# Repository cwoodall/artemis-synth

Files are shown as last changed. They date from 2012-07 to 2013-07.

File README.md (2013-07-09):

# Artemis Synthesizer 

v2.0 Rev C for Summer 2013

Christopher Woodall  
Eric Hazen  
Sam Damask

## Hardware

Schematic and PCB files were made using KiCAD. Gerber files and PDFs are available. The schematic files were created using a 25 mil grid and are sometimes off by 25 mils from the 50 mil grid. It is advised that you also use a 25 mil grid when editing the schematic files.

There is a basic convention for digital signals on the PCB layout, which is the bottom layer travels vertically and the top layer travels horizontally. The analog section, which takes up the left most part of the board routes all signals on the top layer so that they have ground right underneath. An improvement would introduce proper isolation technology.

## Firmware

## Documentation

[Current Documentation](http://ohm.bu.edu/cgi-bin/edf/SoundSynthesizer)

## Versioning

The basic versioning method is `Version NUM Rev LETTER (vNUMrLETTER)`. The version number indicates major version changes (and more importantly the associated software version). The revision letter marks the board revision and does not restart with new versions.

Branched projects are allowed to restart revision numbering and version numbering so long as the name of the project changes in some manner. This is requested to prevent confusion.

## Licensing

(c) Christopher Woodall 2012-2013, under a Creative Commons Attribution-ShareAlike 3.0 Unported License.

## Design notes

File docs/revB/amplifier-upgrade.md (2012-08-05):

Need new Audio Amplifier set up....

Try:
* NJM2076D: http://www.digikey.com/product-detail/en/NJM2076D/NJM2076D-ND/638901
* TEA2025B: http://www.digikey.com/product-detail/en/TEA2025B/497-3991-5-ND/715905
* TBD820M: http://www.digikey.com/product-search/en?x=0&y=0&lang=en&site=us&KeyWords=TBA820m

- Offer a speaker and an audiojack (Audio Jack w/ switch)

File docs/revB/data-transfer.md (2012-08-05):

Optoloader is wonderful and cool, but we have a USB link.

Look into using it as a mass storage device, load up a file of some sort generated by online stuff to that... Should work ok... Would allow for arbitrary waveforms

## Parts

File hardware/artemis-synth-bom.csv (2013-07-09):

# of Boards | 30
REFERENCE | VALUE | DISTRIBUTOR | DISTRIBUTOR # | QUANTITY per Board | Total Quantity | Unit Cost (w/ Price Breaks) | Total Cost (per board) | Digikey Ea | Digikey Total | Our total | Diff
BT1 | BATTERY | Digikey | SBH321AS-ND | 1 | 30 | 1.64 | 1.64 | 1.998 | $59.94 | $49.20 | $10.74
C1, C6 | 10uF | Digikey | 399-6100-ND | 2 | 60 | 0.114 | 0.228 | 0.0646 | $3.88 | $6.84 | -$2.96
C2,C3,C4,C5 | .1uF | Digikey | BC2665CT-ND | 4 | 120 | 0.07072 | 0.28288 | 0.0984 | $11.81 | $8.49 | $3.32
D1 | LED GREEN 3MM | Digikey | 754-1217-ND | 1 | 30 | 0.0808 | 0.0808 | 0.0808 | $2.42 | $2.42 | $0.00
D2 | AMBIENT LIGHT SENSOR 3MM 570NM | Digikey | 751-1057-ND | 1 | 30 | 0.4804 | 0.4804 | 0.4804 | $14.41 | $14.41 | $0.00
D3, D4, D5, D6, D7, D8, D9. D10 | RED LED 3mm | Digikey | 754-1219-ND | 8 | 240 | 0.0675 | 0.54 | 0.0743 | $17.83 | $16.20 | $1.63
IC1 | ATMEGA328P | Digikey | ATMEGA328P-PU-ND | 1 | 30 | 0 | 0 | 1.9832 | $59.5 | $0.00 | $59.50
IC1-SOCKET | 28 Pin .3" PDIP Socket | Digikey | A100210-ND | 1 | 30 | 0.411 | 0.411 | 0.411 | $12.33 | $12.33 | $0.00
J1 | AVR-ISP-6 (2x3 .1” header) | Digikey | 952-1921-ND | 1 | 30 | 0.234 | 0.234 | 0.234 | $7.02 | $7.02 | $0.00
J2 | CONN JACK STEREO R/A 3PIN 3.5MM | Digikey | CP1-3523N-ND | 1 | 30 | 0.58 | 0.58 | 0.588 | $17.64 | $17.40 | $0.24
R1 | 220 Ohm 1/4" Mini | Digikey | S220QCT-ND | 1 | 30 | 0.055 | 0.055 | 0.055 | $1.65 | $1.65 | $0.00
R2,R3,R6 | 100K Ohm 1/4" Mini | Digikey | S100KQTR-ND | 3 | 90 | 0.03 | 0.09 | 0.03 | $2.7 | $2.70 | $0.00
R4 | 10K Ohm 1/4" Mini | Digikey | S10KQTR-ND | 1 | 30 | 0.055 | 0.055 | 0.055 | $1.65 | $1.65 | $0.00
R5, R9 | 47K Ohm 1/4" Mini | Digikey | S47KQTR-ND | 2 | 60 | 0.055 | 0.11 | 0.03 | $1.8 | $3.30 | -$1.50
R7,R8 | 1K Ohm 1/4" Mini | Digikey | S1KQTR-ND | 3 | 90 | 0.03 | 0.09 | 0.03 | $2.7 | $2.70 | $0.00
RV1 | 1K Thumbwheel Pot | Digikey | 3352T-1-102LF | 1 | 30 | 1.395 | 1.395 | 1.1664 | $34.99 | $41.85 | -$6.86
SW1, SW2, SW3, SW4, SW5, SW6, SW7, SW8, SW9, SW10 | SWITCH_PUSH_CW | Digikey | CKN9140-ND | 10 | 300 | 0.2794 | 2.794 | 0.3588 | $107.64 | $83.82 | $23.82
U1 | MCP4921 | Digikey | MCP4921-E/P-ND | 1 | 30 | 1.97 | 1.97 | 1.64 | $49.2 | $59.10 | -$9.90
U1-SOCKET | 8 pin .3" PDIP Socket | Digikey | A100204-ND | 1 | 30 | 0.18 | 0.18 | 0.181 | $5.43 | $5.40 | $0.03
STANDOFFS | STANDOFF RD 4-40THR .750"L ALUM | Digikey | 3481K-ND | 4 | 120 | 0.3244 | 1.2976 | 0.3034 | $36.41 | $38.93 | -$2.52
Total (per Board) | 12.51368
Total | 375.4104 |  |  |  |  |  |  |  | $450.95 | $375.41 | $75.5396

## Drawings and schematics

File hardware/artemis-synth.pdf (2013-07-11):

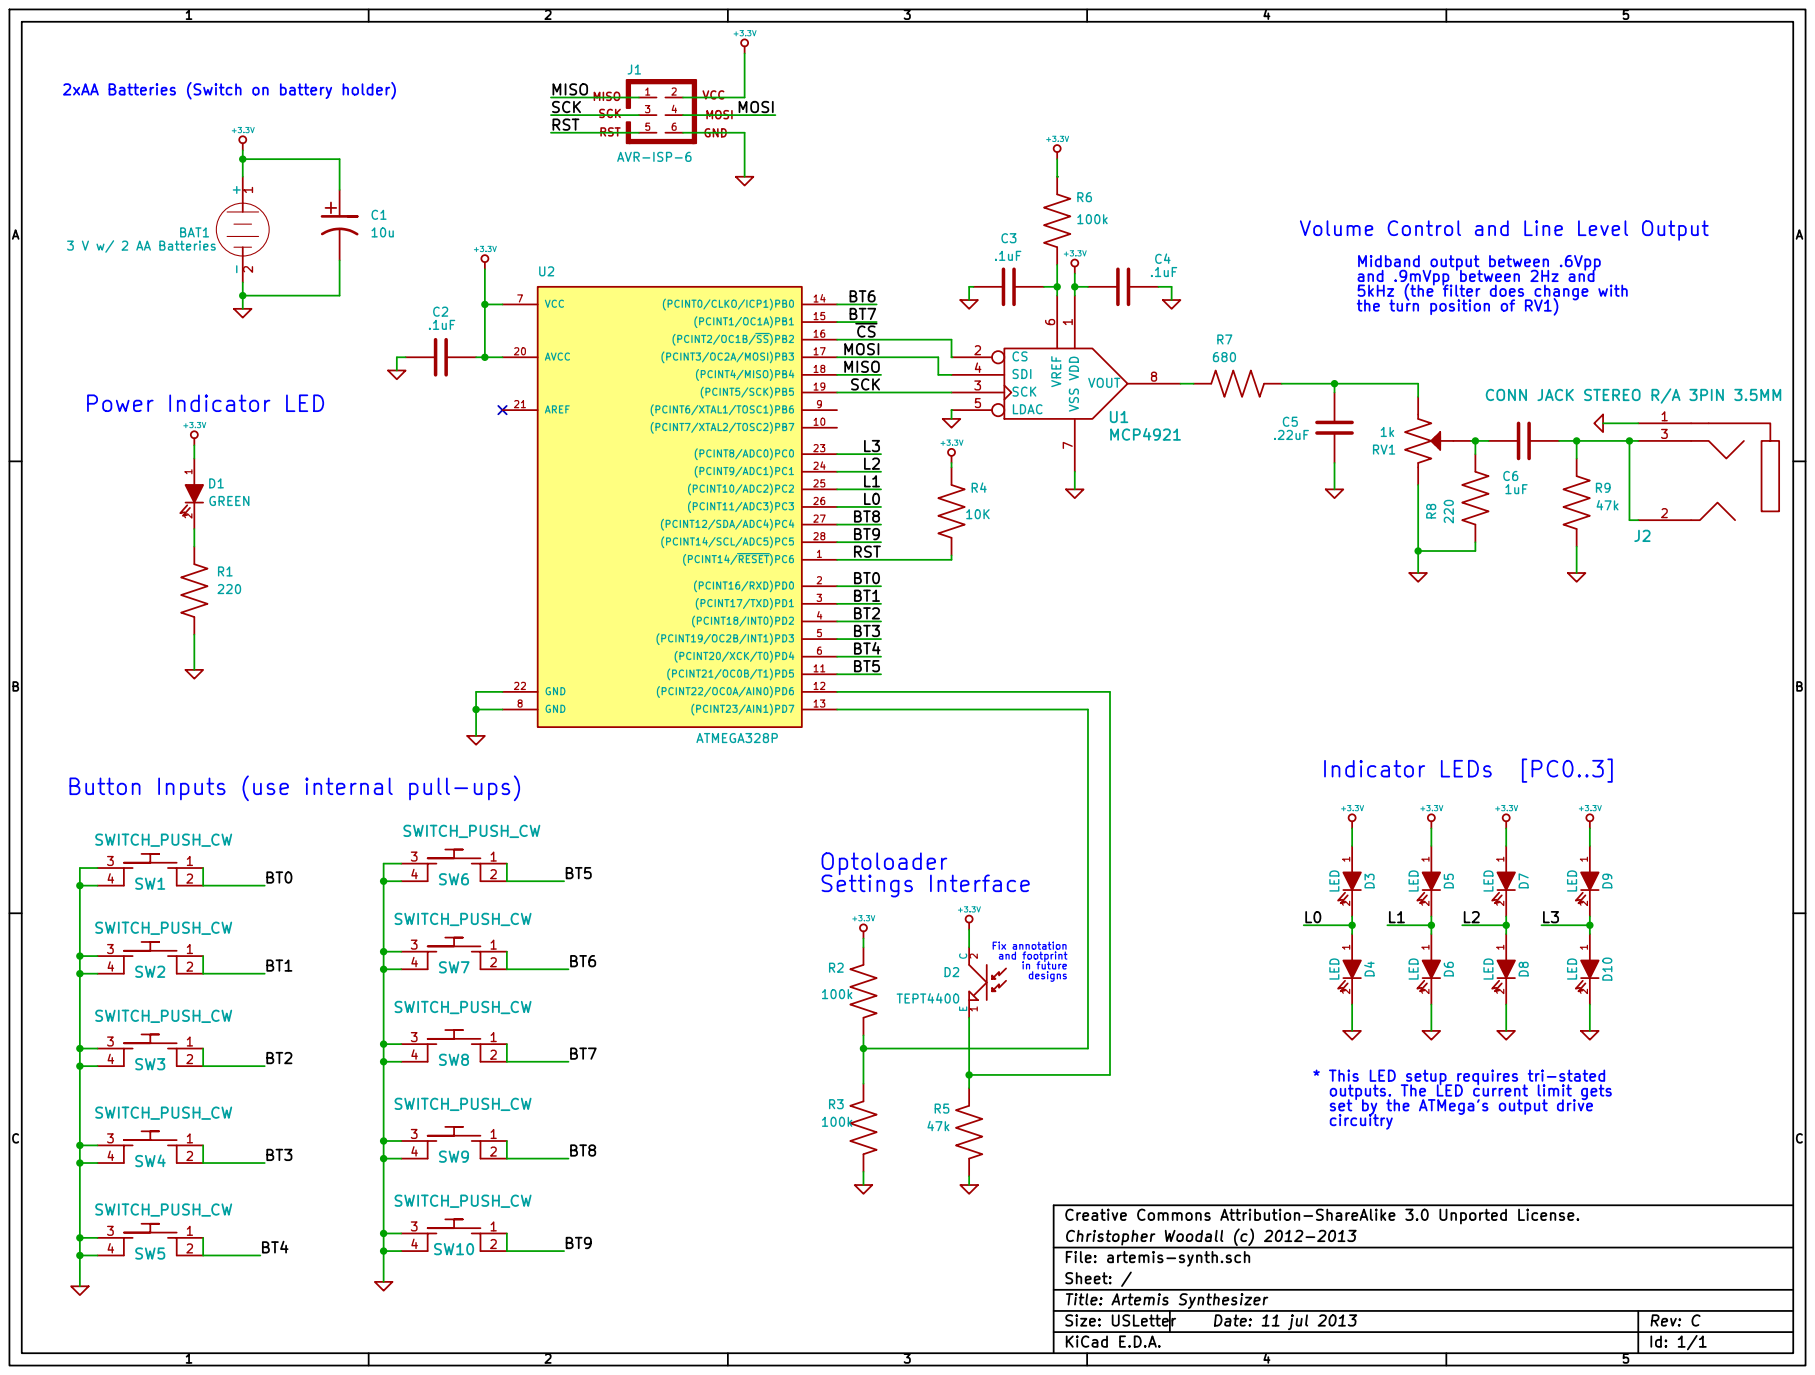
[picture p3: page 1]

+3.3V 2xAA Batteries (Switch on battery holder)

Volume Control and Line Level Output

Midband output between .6Vpp
and .9mVpp between 2Hz and
5kHz (the filter does change with
the turn position of RV1)

* This LED setup requires tri-stated
outputs. The LED current limit gets
set by the ATMega's output drive
circuitry

Creative Commons Attribution-ShareAlike 3.0 Unported License.
Christopher Woodall (c) 2012-2013
File: artemis-synth.sch
Sheet: /
Title: Artemis Synthesizer
KiCad E.D.A.

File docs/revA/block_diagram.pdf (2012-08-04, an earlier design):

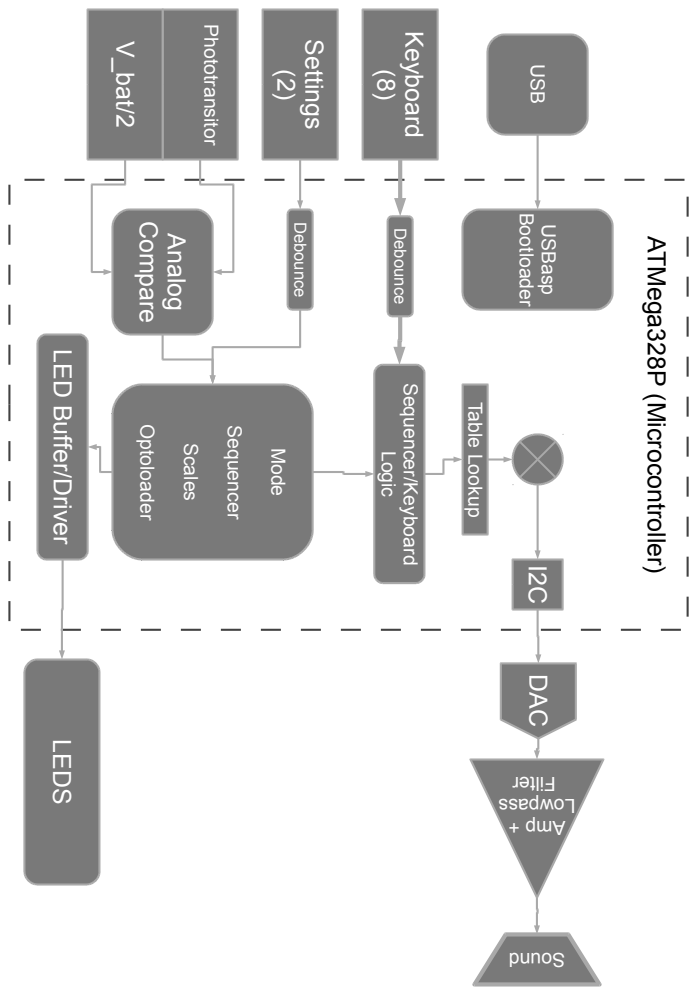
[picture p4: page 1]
ATMega328P (Microcontroller); Keyboard; Sequencer/Keyboard; Logic Debounce; Table Lookup; Settings (2) Debounce; Phototransitor; V_bat/2; Analog; Compare; Mode; Sequencer; Scales; Optoloader; USBasp; Bootloader USB

LED Buffer/Driver LEDS

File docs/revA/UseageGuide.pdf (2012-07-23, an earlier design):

# Keyboard Mode

# ARTEMIS Synthesizer Usage Guide

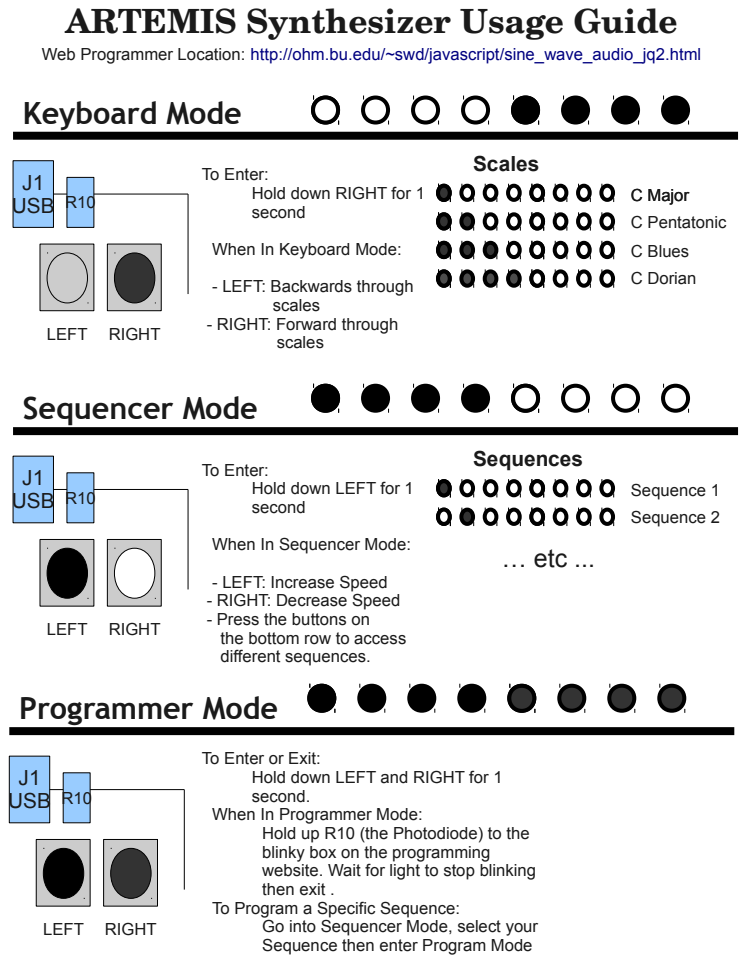
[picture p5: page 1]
USB; LEFT RIGHT; scales; Scales; C Major C Pentatonic; C Blues C Dorian; Sequencer Mode; Sequences; Sequence 1 Sequence 2; … etc ...; J1 USB R10; Programmer Mode

Web Programmer Location: http://ohm.bu.edu/~swd/javascript/sine_wave_audio_jq2.html

To Enter:
Hold down RIGHT for 1
second

When In Keyboard Mode:

- LEFT: Backwards through

- RIGHT: Forward through

Hold down LEFT for 1

When In Sequencer Mode:

- LEFT: Increase Speed
- RIGHT: Decrease Speed
- Press the buttons on
the bottom row to access
different sequences.

To Enter or Exit:
Hold down LEFT and RIGHT for 1
second.
When In Programmer Mode:
Hold up R10 (the Photodiode) to the
blinky box on the programming
website. Wait for light to stop blinking
then exit .
To Program a Specific Sequence:
Go into Sequencer Mode, select your
Sequence then enter Program Mode

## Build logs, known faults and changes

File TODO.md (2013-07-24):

# TODO

* Fix D2 footprint to represent what it really is and also make long lead == square hole. (long lead goes to E)

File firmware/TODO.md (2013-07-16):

# TODO LIST

* Make one button switch scales and the other octaves

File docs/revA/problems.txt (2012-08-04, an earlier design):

<h1 id="problems">Problems:</h1>

<ul>
<li>We did not have 28-pin sockets so we used 2 14 pin sockets so some were not aligned properly. Check your BOM for parts and dimensions!</li>
<li>No 8 pin sockets so if the DAC or Amp were put in wrong a lot of effort needed to go into rework. SOCKET ALL PINS.</li>
<li>Some had issues getting R10 into place correctly and bending. It is a polarized part and needs to be put in right; however, the polarization is not labeled. Needs to be redesigned in future revisions. This will simplify the instructions</li>
<li>Volume too low for the most part. Needs to be fixed in future revisions. A constant complaint.</li>
<li>Web programming rig was effective, but I have some concerns about the actual usability of it. It is slow, and can be unreliable.</li>
</ul>

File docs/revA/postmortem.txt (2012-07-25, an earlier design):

# Post Mortem

## Project Timeline Review

### Brainstorm (June 12-15th)
We decided to develop a project of our own on June 12, 2012. At which point we
presented a few basic options for the project. The two competitors were a 
**Game of Life simulator** or a **synthesizer**. By June 15th we decided on the
synthesizer, ordered test components, decided on a microprocesor and were ready
to start the prototyping stages. 

### Prototypes (June 18th-22nd)

The audio amplifier was prototyped on perfboard
by June 20th and written up [here](http://happyrobotlabs.com/posts/project/artemis-synthesizer-1-testing-the-tda2822-audio-amplifier/).
The TDA2822 test was successful, but the volume output of the speaker was low 
and as would be noted later was not very impressive

The MCP4921 was prototyped and documented [here](http://happyrobotlabs.com/posts/project/artemis-synthesizer-2-interfacing-with-the-mcp4921-spi-dac/).
The process was very swift and there were no major problems. Powering the SPI 
bus from the arduino which was 5V based required power limiting resistors.

### Schematic and PCB layout (June 25-July 6)

Most of the schematic layout was done during the prototyping stages in KiCAD.
KiCAD was very easy to use, but I needed to upgrade to the latest version in
order for it to be especially useable. Schematic layout went without a hitch.

PCB layout started once all the parts were chosen a BOM was made up and 
everything was layed out. PCB orders went out to Sierra Circuits and after
some tweaking to their rules and limits we were able to print with them. 
However, upon receiving the boards there was one trace shorted to the 3.3V
plane making the USB bootloader unuseable on this board. This problem was 
limited to one board and after testing most of the rest was not reproduceable.
In the future, I would increase the boundary between traces and planes and 
possibly avoid power planes for simple designs. 

There were some funding problems since the PCB boards ended up costing around
$15 per and parts also costed nearly $15 per board. The BOM cost was rather 
high for this project and an inspection should be carried out to find cost 
reductions for future revisions of the board.

### Firmware (July 12-20) 

Firmware development went well. Code could be better commented. Needs to be 
cleaned. Make sure comment frequently in future projects and write libraries
for the various "peripherals" you use (internal or external). If you have good
interfaces/drivers then other people can use your board even if your base 
firmware is a little sketchy.

Also, figure out a way to formalize different program states/tasks/programs with
efficient memory management. First time using interrupts heavily. Make sure 
interrupts, especially timer interrupts, are small. There are times when
interrupts can be lengthy, but be cautious and evaluate everything that could 
happen while that interrupt is happening and make the system as robust as 
possible.

### Packing (July 18-20)

Packing went smoothly, but took a lot of work. Need to make sure you put exactly
the right number of parts in. To many confuses people and to few makes the kit
impossible to complete correctly.

We also found some BOM errors. Always check your footprints!

## Additional Problems and Comments

* Audio quiet. Inspect whole audio amplification circuit. Possibly look for a new 
  speaker.

* BOM cost was high.
  * Possibly remove DAC use PWM instead
  * Possibly smaller microcontroller ATMega168 or ATMega88 vs ATMega328

* During soldering many had IC problems
  * Buy the correct sockets
  * Socket all ICs not just the MCU makes, rework easier.

* R10 is polarized, but not labelled as such. Rework Optoloader circuit

* Optoloader speed problems. A very slow data transmission.
  * Possibly use 2 photodiodes (separate clock and data lines)
  * Possibly use multiple colors (interesting solution, but likely expensive)
  * Ditch javascript and try flash, gifs, movies, etc.
  * If speeds can be significantly improved, then we can start programming more 
    complex things over the link.

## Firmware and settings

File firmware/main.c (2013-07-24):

/** 
 *  Artemis Synthesizer v2.00 Firmware
 *  Date: 2013-07-15  
 *
 *  Copyright (c) 2012-2013 Christopher Woodall 
 *  MIT License
 */
#define F_CPU 8000000 // Used to run at 16MHz, but removed XTAL now runs at 8kHz
#include <avr/io.h>
#include <avr/interrupt.h>
#include <util/atomic.h>
#include <avr/eeprom.h> 

#include "HRL_SPI.h"
#include "HRL_MCP492x.h"
#define MCP492x_CONFIG 0x30 // Define configuration bits for MCP4921, that we are going to use

#include "notes.h"
#include "inst.h"
#include "buttons.h"
#include "leds.h"
#include "optoloader.h"

uint8_t opto_enable_ctr = 0;
uint8_t keyboard_ctr = 0;
uint8_t sequencer_ctr = 0;
uint8_t msg_ctr = 0;
uint8_t speed = 0x5F;

#define KEYBOARD  0x01
#define SEQUENCER 0x02
#define BLINKING  0x03
#define OPTOLOADER 0x04 // Currently not used, maintianed by optoloader.flag...
uint8_t mode = KEYBOARD;

#define SEQUENCER_LENGTH 8
#define TOTAL_SEQUENCES 8
uint8_t sequencer_i = 0;

//#define SEQUENCER_ee (const void*)12
uint8_t EEMEM sequencer_ee[TOTAL_SEQUENCES][SEQUENCER_LENGTH] = {
	{0,0,0,0,0,0,0,0},
	{0,0,0,0,0,0,0,0},
	{0,0,0,0,0,0,0,0},
	{0,0,0,0,0,0,0,0},
	{0,0,0,0,0,0,0,0},
	{0,0,0,0,0,0,0,0},
	{0,0,0,0,0,0,0,0},
	{0,0,0,0,0,0,0,0}
};

uint8_t EEMEM first_ee = 0x00;

uint8_t sequencer[TOTAL_SEQUENCES][SEQUENCER_LENGTH] = {
	{0,0,0,0,0,0,0,0},
	{0,0,0,0,0,0,0,0},
	{0,0,0,0,0,0,0,0},
	{0,0,0,0,0,0,0,0},
	{0,0,0,0,0,0,0,0},
	{0,0,0,0,0,0,0,0},
	{0,0,0,0,0,0,0,0},
	{0,0,0,0,0,0,0,0}
};

uint8_t sequencer_display_i = 0;
uint8_t sequencer_metronome = 0;
uint8_t sequencer_metronome_ctr = 0;
uint8_t sequencer_flag = 0;

// WAVE/HARMONICS stuff
uint16_t harmonics[256];
uint16_t harmonics_amplitudes[5] = {0,0,0,0,0};

// LED, Optoloader and Keyboard globals
uint8_t led_refresh_flag = 0;
uint8_t led_display = 0x00000000;
optoloader_t optoloader;
uint8_t read_keyboard_flag = 0;
uint8_t settings_debounce = 0;

#define MAX_LOOKUP  0x7FFF
// Change to inline function
#define GET_WAVE_VALUE(inst, num) (poly_buffer[num]?inst[inc[num]>>NOTES_BASE]:0)
// Change to inline function
#define INCREMENT_NOTE(note, i)                 \
	if (note)									\
    {                                           \
		if (i + note < MAX_LOOKUP)				\
        {                                       \
			i += note;							\
        }                                       \
		else									\
        {                                       \
			i = note - (MAX_LOOKUP - i);		\
        }                                       \
    }                                           \
	else										\
    {                                           \
		i = 0;									\
    }							

// Setup Sample rate at 11kHz, externally we filter at 5.5kHz
// this satisfies Nyquist and technically we should be able
// to accurately reconstruct waves up to 5.5kHz, more than enough 
// for this application.
void setupSampleRate11kHz();

// Setup controls timer at a much lower frequency (near 300Hz)
void setupControlTimer();

#define SCALE_LENGTH 8
uint8_t scale_i = 0;
uint16_t scales[4][SCALE_LENGTH] = {
  {C5, D5, E5, F5, G5, A5, B5, C6},
  {C5, D5, E5, G5, A5, C6, D6, E6},
  {C5, Ds5, F5, Fs5, G5, As5, C6, Ds6},
  {C5, D5, Ds5, F5, G5, A5, As5, C6}
};

uint16_t poly_buffer[8] = {0,0,0,0,0,0,0,0};
uint8_t poly_i = 0;
uint8_t key_pressed;
uint8_t debounce = 0;

inline uint8_t shiftOnes(uint8_t a) 
{
	uint8_t output = 0;
	uint8_t i = 0;
	for (i = 0; i < a; i++) {
		output |= (1<<i);
	}
	return output;
}

int main(void)
{
	// Disable Interrupts for setup
	cli();
	
	// By default load a sine_table wave into harmonic 
	// [*] replace with EEPROM reads
	for (int i = 0; i < 256; i++) {
		harmonics[i] = sine_table[i];
    }
	
	first_ee = eeprom_read_byte(&first_ee);
	if (first_ee == 0xFF) {
		eeprom_write_byte(&first_ee,0x33);
		eeprom_write_block((const void *)sequencer, (void *)sequencer_ee, 64);
    } else {
		// Load up sequencer information from ee_prom
		eeprom_read_block((void*)sequencer, (const void *)sequencer_ee, 64);
    }
	
	// Setup Timer2, which is our "control timer"
	setupControlTimer();
	
	// SETUP BUTTON INPUTS
	setupButtons();
	
	// Setup the SPI Bus
	setupSPI(SPI_MODE_0, SPI_MSB, SPI_NO_INTERRUPT, SPI_MASTER_CLK2);
	SETUP_DAC;
	
	// Setup Timer1 to work at 22KHz sample rate
	// This is our sample rate for the output audio
	setupSampleRate11kHz(); 
  
	// Initialize display for keyboard mode
	led_display = setupDisplay();
	setDisplay(&led_display, shiftOnes(scale_i+1));  
	
	// Initialize Optoloader and then turn it off
	optoloader = setupOptoloader();
	disableOptoloader(&optoloader);
	
	// For storing settings button presses
	uint8_t settings = 0;
	uint8_t settings_prev = 0;
	uint8_t keyboard = 0;
	uint8_t keyboard_prev = 0;
	
	
	sei(); // Enable Interrupts now that we are all ready to go
	for(;;) {
		updateDisplay(&led_display, &led_refresh_flag);
		
		settings = readSettings();
		// Check if we are in Optoloader mode (active Optoloader)
		if (optoloader.flags & OPTO_ACTI_bm) {
			if (settings_debounce == 0) {	
				if ((settings == 0) && (settings_prev != 0)) {
					opto_enable_ctr = 1;
					settings_debounce = 1;
				} else if ((settings != 0) && (settings_prev == 0))	{
					settings_debounce = 1;
					opto_enable_ctr = 0;
				}
			}	  
		} else {
			if ((settings == 0) && (opto_enable_ctr == 0)) {
				opto_enable_ctr = 1;
				sequencer_ctr = 0;
				keyboard_ctr = 0;
			} else if (settings) {
				opto_enable_ctr = 0;
				if (!(settings & 0x02) && (sequencer_ctr == 0))	{
					sequencer_ctr = 1;
				} else if (settings & 0x02)	{
					sequencer_ctr = 0;
				}
				if (!(settings & 0x01) && (keyboard_ctr == 0)) {
					keyboard_ctr = 1;
				} else if (settings & 0x01)	{
					keyboard_ctr = 0;
				}
			}
	  
			if (mode == KEYBOARD) {
				if (settings_debounce == 0)	{	
					if (((settings & 0x01) == 0) && ((settings_prev & 0x01) != 0)) { 
						if (scale_i < 3) {
							scale_i += 1;
						} else {
							scale_i = 0;
						}
						settings_debounce = 1;
						setDisplay(&led_display, shiftOnes(scale_i+1));
					}
					if (((settings & 0x02) == 0) && ((settings_prev & 0x02) != 0)) {
						if (scale_i > 0) {
							scale_i -= 1;
						} else {
							scale_i = 3;
						}
						setDisplay(&led_display, shiftOnes(scale_i+1));		  
						settings_debounce = 1;
					}
				}
				if (read_keyboard_flag) {
					read_keyboard_flag = 0;
					keyboard = readKeyboard();
					
					// Prevent the following array accesses to be disturbed, otherwise you get nasty sounds
					ATOMIC_BLOCK(ATOMIC_RESTORESTATE) {
						poly_buffer[0] = 0;
						poly_buffer[1] = 0;
						poly_buffer[2] = 0;
						poly_buffer[3] = 0;
						poly_buffer[4] = 0;
						poly_buffer[5] = 0;
						poly_buffer[6] = 0;
						poly_buffer[7] = 0;
						
						poly_i = 0;
						
						for (uint8_t j = 0; j < 8; j++) {
							if (((keyboard & (0x01 << j)) == 0) && (poly_i <= 3)) {
								poly_buffer[poly_i] = scales[scale_i][j];
								poly_i += 1;
							}
						}
					}
				}
			} else if (mode == SEQUENCER) {
				//setDisplay(&led_display, sequencer_metronome);
				setDisplay(&led_display, shiftOnes(sequencer_i+1));
				
				keyboard = readKeyboard();
				if (settings_debounce == 0)	{
					if (((settings & 0x02) == 0) && ((settings_prev & 0x02) != 0)) { 
						if (speed < 0xCF) {
							speed += 0x10;
						} else {
							speed = 0xCF;
						}
						settings_debounce = 1;
						setDisplay(&led_display, shiftOnes(scale_i+1));
					}

					if (((settings & 0x01) == 0) && ((settings_prev & 0x01) != 0)) {
						if (speed > 0x2F) {
							speed -= 0x10;
						} else {
							speed = 0x2F;
						}
						settings_debounce = 1;
					} 

					if (((keyboard & 0x01)==0) && ((keyboard_prev & 0x01) != 0)) {
						sequencer_i = 0;
						settings_debounce = 1;
					}
					if (((keyboard & 0x02)==0) && ((keyboard_prev & 0x02) != 0)) {
						sequencer_i = 1;
						settings_debounce = 1;
					}
					if (((keyboard & 0x04)==0) && ((keyboard_prev & 0x04) != 0)) {
						sequencer_i = 2;
						settings_debounce = 1;
					}

					if (((keyboard & 0x08)==0) && ((keyboard_prev & 0x08) != 0)) {
						sequencer_i = 3;
						settings_debounce = 1;
					}

					if (((keyboard & 0x10)==0) && ((keyboard_prev & 0x10) != 0)) {
						sequencer_i = 4;
						settings_debounce = 1;
					}

					if (((keyboard & 0x20)==0) && ((keyboard_prev & 0x20) != 0)) {
						sequencer_i = 5;
						settings_debounce = 1;
					} 

					if (((keyboard & 0x40)==0) && ((keyboard_prev & 0x40) != 0)) {
						sequencer_i = 6;
						settings_debounce = 1;
					} 

					if (((keyboard & 0x80)==0) && ((keyboard_prev & 0x80) != 0)) {
						sequencer_i = 7;
						settings_debounce = 1;
					}
				}
				keyboard_prev = keyboard;
				poly_i = 4;
				
				ATOMIC_BLOCK(ATOMIC_RESTORESTATE) {
					sequencer_flag = 0;
					if (sequencer[sequencer_i][sequencer_metronome] & (1<<0)) {
						poly_buffer[0] = C5;
					} else {
						poly_buffer[0] = 0;
					} 
					if (sequencer[sequencer_i][sequencer_metronome] & (1<<1)) {
						poly_buffer[1] = D5;
					} else {
						poly_buffer[1] = 0;
					}
					if (sequencer[sequencer_i][sequencer_metronome] & (1<<2))	{
						poly_buffer[2] = E5;
					} else {
						poly_buffer[2] = 0;
					}
					if (sequencer[sequencer_i][sequencer_metronome] & (1<<3))	{
						poly_buffer[3] = F5;
					} else {
						poly_buffer[3] = 0;
					}
					if (sequencer[sequencer_i][sequencer_metronome] & (1<<4))	{
						poly_buffer[4] = G5;
					} else {
						poly_buffer[4] = 0;
					} 
					if (sequencer[sequencer_i][sequencer_metronome] & (1<<5))	{
						poly_buffer[5] = A5;
					} else {
						poly_buffer[5] = 0;
					}
					if (sequencer[sequencer_i][sequencer_metronome] & (1<<6))	{
						poly_buffer[6] = B5;
					} else {
						poly_buffer[6] = 0;
					}
					if (sequencer[sequencer_i][sequencer_metronome] & (1<<7))	{
						poly_buffer[7] = C6;
					} else {
						poly_buffer[7] = 0;
					}
				}
			}
		}
		settings_prev = settings;
	}
	return 0;
}

void setupControlTimer()
{    
	TCCR2A = 0;     // set entire TCCR1A register to 0
	TCCR2B = 0;     // same for TCCR1B
	TIMSK2 = 0;
	TCNT2 = 0;

	// target_freq = 306.4 Hz
	// timer_res = 1/16MHz
	// prescaler = 1024
	// timer_counts = (1.0/target_freq)/(timer_res*prescaler) - 1
	OCR2A = 50; 
  
	// Turn on CTC mode
	TCCR2A |= (1 << WGM21);
	// set CS20, CS21 & CS22 for 1024 precaler
	TCCR2B |= (1 << CS20);
	TCCR2B |= (1 << CS21);
	TCCR2B |= (1 << CS22);

	// Enable interrupts
	TIMSK2 |= (1 << OCIE2A);
}

ISR(TIMER2_COMPA_vect)
{
	read_keyboard_flag = 1;
	if (optoloader.flags & OPTO_ACTI_bm) {
		optoloader.counter += 1;
		if (opto_enable_ctr == 0xFF) {
			optoloader.flags &= ~OPTO_ACTI_bm;
			setDisplay(&led_display, shiftOnes(scale_i+1));
			disableOptoloader(&optoloader);
			opto_enable_ctr = 0;
			
			eeprom_write_block((const void *)sequencer, (void *)sequencer_ee, 64);

			setupSampleRate11kHz();
		} 
		
		if (opto_enable_ctr > 0) {
			opto_enable_ctr += 1;
		}      
	} else {
		if (opto_enable_ctr == 0xFF) {
			optoloader.flags |= OPTO_ACTI_bm;
			setDisplay(&led_display, 0xFF);
			TCNT2 = 0;      
			TCCR1B = 0;
			enableOptoloader(&optoloader);
			opto_enable_ctr = 0;
			msg_ctr = 0;
		} else if (opto_enable_ctr > 0) {
			opto_enable_ctr += 1;
		}

		if (sequencer_ctr == 0xFF) {
			setDisplay(&led_display, 0x0F);
			sequencer_ctr = 0;
			mode = SEQUENCER;
		} else if (sequencer_ctr > 0) {
			sequencer_ctr += 1;
		}

		if (keyboard_ctr == 0xFF) {
			setDisplay(&led_display, 0xF0);
			keyboard_ctr = 0;
			mode = KEYBOARD;
		} else if (keyboard_ctr > 0) {
			keyboard_ctr += 1;
		}

		if (mode == SEQUENCER) {
			sequencer_metronome_ctr += 1;
			if ((sequencer_metronome_ctr >= speed) && !(sequencer_metronome % 2)) {
				sequencer_metronome += 1;
				sequencer_metronome_ctr = 0;
				sequencer_flag = 1;
			} else if ((sequencer_metronome_ctr >= (speed-0x05))) {
				sequencer_metronome += 1;
				sequencer_metronome_ctr = 0;
				sequencer_flag = 1;
			} 

			if (sequencer_metronome > 7){
				sequencer_flag = 1;
				sequencer_metronome = 0;
			}
		}
	}

	if (settings_debounce == 30) {
		settings_debounce = 0;
	} else if (settings_debounce >= 1) {
		settings_debounce += 1;
	}

	led_refresh_flag ^= 0x01;
	led_refresh_flag |= 0x02;
}

ISR(ANALOG_COMP_vect)
{
	static uint8_t num_bytes = 0; // number of bytes expected to be received

	static uint32_t temp_harmonics = 0;
	static uint8_t msg_mode = 0; 
	// Turn off Timer 2 Interrupt A
	TIMSK2 &= ~(1<<OCIE2A);
	// Reset Timer2 Counter
	TCNT2 = 0;

	// Get optoloader information
	runOptoloader(&optoloader, &led_display);

	// When we have a full byte, read it out and display it.
	if (optoloader.message_count == 8) {
		optoloader.message_count = 0;
		led_display = optoloader.message;

		// NEED TO FINISH WRITING MESSAGE INTERPRETATION STUFF
		if (msg_ctr == 0) {
			if (optoloader.message & SEQUENCER_MSG) {
				// if we are getting a sequencer message do something here
				msg_mode = SEQUENCER_MSG;
			} else if (optoloader.message & HARMONICS_MSG) {
				// if we are getting a harmonics message do the appropraite thing here
				msg_mode = HARMONICS_MSG;
			} //else {
				// ERROR STATE!!!
//			}
			// How many bytes before epilogue?
			num_bytes = 0x0F & optoloader.message;
		} else if (msg_ctr > num_bytes)	{
			if (optoloader.message == EPILOGUE_MSG)	{ 
				if (msg_mode == HARMONICS_MSG)	{
					for (uint16_t i = 0; i < 256; i++) {
						// Simplify this code...
						// Also % 256 -> and 255 (& 255)
						temp_harmonics = (((harmonics_amplitudes[0]*(sine_table[i]<<2))>>4) + 
															((harmonics_amplitudes[1]*(sine_table[(i*2)%256]<<2))>>4) + 
															((harmonics_amplitudes[2]*(sine_table[(i*4)%256]<<2))>>4) + 
															((harmonics_amplitudes[3]*(sine_table[(i*8)%256]<<2))>>4) + 
															((harmonics_amplitudes[4]*(sine_table[(i*16)%256]<<2))>>4))/5;

						harmonics[i] = (uint16_t) temp_harmonics;
					}
				}
				opto_enable_ctr = 0xFF;
			}
		} else if (msg_ctr > 0) {
			if (msg_mode == SEQUENCER_MSG) {
				sequencer[sequencer_i][msg_ctr-1] = optoloader.message;
			} else if (msg_mode == HARMONICS_MSG) {
				harmonics_amplitudes[(optoloader.message>>5)] = (optoloader.message>>2) & 0x07;
			}
		}
		msg_ctr += 1;
	}
	
	TIMSK2 |= (1<<OCIE2A);
}

void setupSampleRate11kHz()
{    
	TCCR1A = 0;     // set entire TCCR1A register to 0
	TCCR1B = 0;     // same for TCCR1B
	
	// set compare match register to desired timer count:
	// We want to compare at 11kHz
	// target time/timer resolution
	// (1/11kHz)/(1/8MHz) = 727
	OCR1A = 727; 
	
	// turn on CTC mode:
	TCCR1B |= (1 << WGM12);
	TCCR1B |= (1 << CS10); // No prescaler
	// enable timer compare interrupt:
	TIMSK1 |= (1 << OCIE1A);
}

   
ISR(TIMER1_COMPA_vect) 
{
	static uint16_t inc[8] = {0, 0, 0, 0, 0, 0, 0, 0};
	static uint16_t final = 0;
	
	INCREMENT_NOTE(poly_buffer[0], inc[0]);
	INCREMENT_NOTE(poly_buffer[1], inc[1]);
  INCREMENT_NOTE(poly_buffer[2], inc[2]);
	INCREMENT_NOTE(poly_buffer[3], inc[3]);
	INCREMENT_NOTE(poly_buffer[4], inc[4]);
	INCREMENT_NOTE(poly_buffer[5], inc[5]);
	INCREMENT_NOTE(poly_buffer[6], inc[6]);
	INCREMENT_NOTE(poly_buffer[7], inc[7]);
	
	final = (GET_WAVE_VALUE(harmonics, 0) + 
					 GET_WAVE_VALUE(harmonics, 1) +
					 GET_WAVE_VALUE(harmonics, 2) +
					 GET_WAVE_VALUE(harmonics, 3) +
					 GET_WAVE_VALUE(harmonics, 4) +
					 GET_WAVE_VALUE(harmonics, 5) +
					 GET_WAVE_VALUE(harmonics, 6) +
					 GET_WAVE_VALUE(harmonics, 7))>>2;
	
	writeMCP492x(final, MCP492x_CONFIG);
}

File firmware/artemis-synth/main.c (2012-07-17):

#define F_CPU 16000000
#include <avr/io.h>
#include <util/delay.h>
#include <avr/interrupt.h>
#include "HRL_SPI.h"
#include "HRL_MCP492x.h"
#define MCP492x_CONFIG 0x30 // Define configuration bits for MCP4921

#include "notes.h"
#include "inst.h"
#include "buttons.h"
#include "leds.h"

uint8_t led_display = 0x00000000;

#define MAX_LOOKUP  0x7FFF
#define INCREMENT_NOTE(note, i) 			\
  if (note)						\
    {							\
      if (i + note < MAX_LOOKUP)			\
        {						\
          i += note;					\
        }						\
      else						\
        {						\
          i = note - (MAX_LOOKUP - i);			\
        }						\
    }							\
  else							\
    {							\
      i = 0;						\
    }							

#define FREQUENCY_TO_COUNT(x) (F_CPU/1000)/(x/1000)

// Setup Sample rate at 22kHz, externally we filter at 11kHz
// this satisfies Nyquist and technically we should be able
// to accurately reconstruct waves up to 11kHz
void setupSampleRate();
void setupControlTimer();

uint8_t read_keyboard_flag = 0;
#define SCALE_LENGTH 8
#define SCALE_NUMBER 4
uint8_t scale_i = 0;
uint16_t scales[SCALE_NUMBER][SCALE_LENGTH] = {
  {C6, D6, E6, F6, G6, A6, B6, C7},
  {C5, D5, E5, G5, A5, C6, D6, E6},
  {C5, Ds5, F5, Fs5, G5, As5, C6, Ds6},
  {C5, D5, Ds5, F5, G5, A5, As5, C6}
};

uint16_t poly_buffer[4] = {0,0,0,0};
uint8_t poly_i = 0;
uint8_t key_pressed;
uint8_t debounce = 0;
uint8_t settings_debounce = 0;

int main(void) 
{
  // Disable Interrupts for setup
  cli();
  
  // SETUP BUTTON INPUTS
  setupButtons();
  
  setupDisplay();

  // Setup the SPI Bus
  setupSPI(SPI_MODE_0, SPI_MSB, SPI_NO_INTERRUPT, SPI_MASTER_CLK2);
  SETUP_DAC;
  setupSampleRate(22000); // Setup Timer1 to work at 22KHz sample rate
  setupControlTimer();

  uint8_t settings = 0;
  uint8_t settings_prev = 0;

  led_display = 0b11111111;

  sei(); // Enable Interrupts now that we are all ready to go

  for(;;) 
    {      
        settings = readSettings();
        if (settings_debounce == 0)
        {

          if (((settings & 0x02) == 0) && ((settings_prev & 0x02) != 0))
            { 
              led_display <<= 1;
              led_display |= 0x01;
              if (scale_i < 3)
                {
                  scale_i += 1;
                }
              else
                {
                  scale_i = 0;
                }
              settings_debounce = 1;
            }
          if (((settings & 0x01) == 0) && ((settings_prev & 0x01) != 0))
            {
              led_display >>= 1;
              if (scale_i > 0) 
                {
                  scale_i -= 1;
                }
              else
                {
                  scale_i = 3;
                }
              settings_debounce = 1;
            }
        }
      settings_prev = settings;
    }
  
  return(0);
}

void setupControlTimer()
{    
  TCCR2A = 0;     // set entire TCCR1A register to 0
  TCCR2B = 0;     // same for TCCR1B
  TIMSK2 = 0;
  TCNT2 = 0;
  // target_freq = 120 Hz
  // timer_res = 1/16MHz
  // prescaler = 1024
  // timer_counts = (1.0/target_freq)/(timer_res*prescaler) - 1
  OCR2A = 129; 

  // Turn on CTC mode
  TCCR2A |= (1 << WGM21);
  // set CS20, CS21 & CS22 for 1024 precaler
  TCCR2B |= (1 << CS20);
  TCCR2B |= (1 << CS21);
  TCCR2B |= (1 << CS22);

  // Enable interrupts
  TIMSK2 |= (1 << OCIE2A);
}

ISR(TIMER2_COMPA_vect)
{
  static uint8_t keyboard = 0;
  static uint8_t j = 0; 
  static uint8_t led_refresh_flag = 0;
  /*
  keyboard = readKeyboard();
  poly_buffer[0] = 0;
  poly_buffer[1] = 0;
  poly_buffer[2] = 0;
  poly_buffer[3] = 0;
  poly_i = 0;
  
  for (j = 0; j < 8; j++) 
    {
      if (((keyboard & (0x01 << j)) == 0) && (poly_i <= 3))
        {
          poly_buffer[poly_i] = scales[scale_i][j];
          poly_i += 1;
        }
    }
    *
  if (settings_debounce > 0)
    {
      (settings_debounce < 20)?(settings_debounce += 1):(settings_debounce = 0);
    }
  

  PORTC &= 0xF0;
  DDRC &= 0xF0;
  if (led_refresh_flag)
    {
      led_refresh_flag = 0;
      if (led_display & 1)
        {
          PORTC &= LED0_m;
          DDRC |= ~LED0_m;
        }
      else
        {
          DDRC &= LED0_m;
        }
      if ((led_display & (1<<2)) != 0)
        {
          PORTC &= LED2_m;
          DDRC |= ~LED2_m;
        }
      else
        {
          DDRC &= LED2_m;
        }
      if ((led_display & (1<<4)) != 0)
        {
          PORTC &= LED4_m;
          DDRC |= ~LED4_m;
        }
      else
        {
          DDRC &= LED4_m;
        }
      if ((led_display & (1<<6)) != 0)
        {
          PORTC &= LED6_m;
          DDRC |= ~LED6_m;
        }
      else
        {
          DDRC &= LED6_m;
        }
    }
  else
    {
      led_refresh_flag = 0xFF;
      if (led_display & (1<<1))
        {
          DDRC |= LED1_m;
          PORTC |= LED1_m;
        }
      else
        {
          DDRC &= ~LED1_m;
        }

      if (led_display & (1<<3))
        {
          DDRC |= LED3_m;
          PORTC |= LED3_m;
        }
      else
        {
            DDRC &= ~LED3_m;
        }
      if (led_display & (1<<5))
        {
          DDRC |= LED5_m;
          PORTC |= LED5_m;
        }
      else
        {
          DDRC &= ~LED5_m;
        }
      if (led_display & (1<<7))
        {
          DDRC |= LED7_m;
          PORTC |= LED7_m;
        }
      else
        {
          DDRC &= ~LED7_m;
        }
    }
}

void setupSampleRate(uint16_t frequency)
{    
  TCCR1A = 0;     // set entire TCCR1A register to 0
  TCCR1B = 0;     // same for TCCR1B
  
  // set compare match register to desired timer count:
  // We want to compare at 22kHz
  // target time/timer resolution
  // (1/22kHz)/(1/16MHz) = 727
  //OCR1A = 727; 
  OCR1A = (uint16_t) FREQUENCY_TO_COUNT(frequency);

  // turn on CTC mode:
  TCCR1B |= (1 << WGM12);
  TCCR1B |= (1 << CS10); // No prescaler
  // enable timer compare interrupt:
  TIMSK1 |= (1 << OCIE1A);
  // enable global interrupts:
}

#define GET_WAVE_VALUE(inst, num) (poly_buffer[num]?inst[inc[num]>>NOTES_BASE]:0)

ISR(TIMER1_COMPA_vect) 
{
  static uint16_t inc[4] = {0, 0, 0, 0};
  static uint16_t final = 0;

  INCREMENT_NOTE(poly_buffer[0], inc[0]);
  INCREMENT_NOTE(poly_buffer[1], inc[1]);
  INCREMENT_NOTE(poly_buffer[2], inc[2]);
  INCREMENT_NOTE(poly_buffer[3], inc[3]);
  
  final = (GET_WAVE_VALUE(channelC, 0) + 
           GET_WAVE_VALUE(channelC, 1) +
           GET_WAVE_VALUE(channelC, 2) +
           GET_WAVE_VALUE(channelC, 3))/poly_i;

  writeMCP492x(final, MCP492x_CONFIG);
}

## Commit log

2012-06-29 saving repo
    [artemis-synth-v1.brd, artemis-synth-v1.sch]
2012-06-29 Added holes
    [artemis-synth-v1.brd]
2012-07-02 Fixed drill file and change USB connector footprint
    [artemis-synth-v1.brd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]
2012-07-02 Made BOM, fixed up board. submitting to Eric for review
    [artemis-synth-v1.brd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]
2012-07-02 Modified PCB layout to remove collisions with sierra pcb's protoexpress.com service. Ran successfully through auto tester without need for human intervention.
    [$artemis-synth-v1.brd, artemis-synth-v1.brd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]
2012-07-03 Reorganizing hardware section
    [$artemis-synth-v1.brd, artemis-synth-v1-bom.csv, artemis-synth-v1-bom.ods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]
2012-07-03 Some minor tweaks to the PCB layout and generated new gerber files for production
    [artemis-synth-v1-Back.gbl, artemis-synth-v1-Front.gtl, artemis-synth-v1-Mask_Front.gts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]
2012-07-03 Updated .gitignore
    [artemis-synth-v1.brd]
2012-07-03 Generated new gerbers for changes
    [artemis-synth-v1.brd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]
2012-07-03 Some cosmetic fixes
    [artemis-synth-v1.brd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]
2012-07-03 new gerber files
2012-07-05 just tweaking the gerbers.zip
2012-07-13 Writing new firmware in folder testing
    [$artemis-synth-v1.sch]
2012-07-13 making progress. Polyphony still a little buggy...
    [main.c]
2012-07-15 All basic features working, need to reduce size of interrupts...
2012-07-17 base optoloader firmware made, needs to be able to receive messages
    [$artemis-synth-v1.sch, artemis-synth-v1.sch]
2012-07-18 added sequencer
    [artemis-synth-v1.sch]
2012-07-19 Firmware, updated some other things...
    [artemis-synth-v1.sch]
2012-07-26 Fixed problem with unpredictable EEPROM... just erase EEPROM, program will take care of EEPROM writes for you :)
    [main.c]
2012-07-26 Added Optoloader autoexit... Need to add Error mode, so that error messages (blinky lights) can be presented, when an error has been encountered
    [main.c]
2012-08-01 fixed bom
    [artemis-synth-v1-bom.csv, artemis-synth-v1-bom.ods]
2012-08-01 FixAdded title and stuff to artemis-synth-v1
    [artemis-synth-v1.sch]
2013-07-02 Took out USB interface. Added power indication LED. Removed external xtal. Removed speaker. Removed output interface. Added line level output and audio jack. All changes are to schematic. PCB layout 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
    [artemis-synth-v1.sch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]
2013-07-03 made a pcb layout for the enw design. It is the same size, but has different text a few different headers and overall less parts.
    [.brd.brd, artemis-synth-v1.sch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]
2013-07-03 Updated naming
    [artemis-synth-v1-bom.csv, artemis-synth-v1-bom.ods, artemis-synth-v1.brd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]
2013-07-03 updated gerber files
    [artemis-synth-v2-Back.gbl, artemis-synth-v2-Front.gtl, artemis-synth-v2-Mask_Back.gbs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]
2013-07-05 fixing up small problems on PCB layout. Finalizing design.
    [artemis-synth-v2.brd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]
2013-07-05 removed -v# from all hardware files... The repo should determine all of the version control. streamline supdating.
    [artemis-synth.brd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]
2013-07-09 Fixed error on D2, in which the collector of the phototransistor was not connected to GND. Also, note that long lead is the Emitter. Fix symbol to make sure it actually represents transistor package 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
    [artemis-synth.brd, artemis-synth.sch]
2013-07-09 Added BOM
    [artemis-synth-bom.csv]
2013-07-09 Corrected BOM
    [artemis-synth-bom.csv]
2013-07-09 Changed D1 Silkscreen. Changed BT1 to BAT1 (battery reference). Changed plane clearance to .02"
    [artemis-synth.brd, artemis-synth.sch]
2013-07-09 Modified versioning
    [artemis-synth.brd, artemis-synth.sch]
2013-07-09 Moved to 8MHz onboard oscillator
    [main.c]
2013-07-11 Generated latest gerber files for the v2rC board. Should be the final changes before getting sent out. Cleared todo list, plotted latest pdf of schematic. Changed output stage to add a pot which appr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
    [artemis-synth.brd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]
2013-07-11 updated gerber files to have the 1pin holes at the edges for mounting
    [artemis-synth.brd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]
2013-07-11 Added Open Source Hardware logo
    [artemis-synth.brd]
2013-07-11 Added oshw logo AND updated gerbers
    [artemis-synth-Back.gbl, artemis-synth-Front.gtl, artemis-synth-Mask_Back.gbs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]
2013-07-11 Finalizing, eric will review
    [artemis-synth-SilkS_Front.gto]
2013-07-16 reorganized firmware directory
    [artemis-synth.sch]
